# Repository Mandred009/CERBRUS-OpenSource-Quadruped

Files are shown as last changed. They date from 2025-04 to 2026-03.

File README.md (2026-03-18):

<table style="width:100%">
  <tr>
    <th width="50%">Physical Hardware</th>
    <th width="50%">MuJoCo Simulation</th>
  </tr>
  <tr>
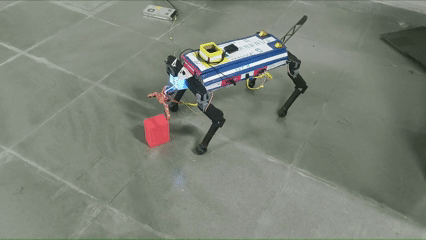
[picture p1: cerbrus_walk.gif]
    <td></td>
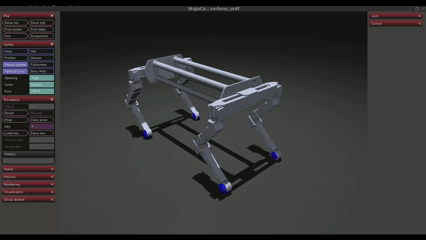
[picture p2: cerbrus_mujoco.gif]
    <td></td>
  </tr>
</table>

# CERBRUS: Open-Source Ant-Inspired Quadruped
**A 14-DoF Bio-Inspired Robot with Front-Mounted Manipulation and ROS 2 Integration. Inspired by nature, engineered for autonomy.**

 



---

## 📋 Overview
Most quadruped robots treat manipulation as a secondary attachment, often resulting in a high center of gravity and reduced stability. **CERBRUS** re-engineers this approach by mimicking **ant morphology**, integrating a **2-DoF gripper at the front "mandibles."** This design optimizes the center of mass for pick-and-place tasks and enables interaction in narrow environments where top-mounted arms traditionally struggle.

> **Note:** This project is currently in active development at the intersection of bio-inspired hardware and autonomous perception.

---

## ✨ Key Features
* **Ant-Inspired Morphology:** Front-mounted 2-DoF gripper for stable, organic manipulation.
* **14 Degrees of Freedom:** 3-DoF per leg + 2-DoF gripper for high-fidelity gait control and interaction.
* **ROS 2 Native:** Built on **Jazzy Jalisco**, utilizing a modular node architecture for telemetry, control, and perception.
* **Active Balancing:** Real-time PID-based posture correction using **BNO055 IMU** data for terrain adaptation.
* **Edge-Ready Compute:** Powered by **Raspberry Pi 5** for high-level logic and Arduino microcontrollers for low-level actuator PWM.

---

## 🛠 Hardware Architecture

| Component | Specification |
| :--- | :--- |
| **Main Processor** | Raspberry Pi 5 (8GB) running Ubuntu 24.04 |
| **Microcontrollers** | Arduino Mega (Gait/Leg Kinematics) & Arduino Nano (Gripper) |
| **Sensors** | Bosch BNO055 (9-axis IMU), Voltage/Current Telemetry |
| **Actuators** | 14x High-torque Metal Gear Servos |
| **Communication** | HC-12 Long Range Radio / Custom Handheld Controller |
| **Chassis** | Modular 3D-printed design optimized for payload-to-weight ratio |

---

## 💻 Software & Installation

### Prerequisites
* **OS:** Ubuntu 24.04 (Noble Numbat)
* **Middleware:** ROS 2 Jazzy Jalisco
* **Language:** Python 3.10+ / C++ 17

### Quick Start
```bash
# Please read the report pasted at the bottom of this page for more details on technical implementation and software design.

# Clone the repository and submodules
git clone --recursive [https://github.com/Mandred009/CERBRUS-OpenSource-Quadruped.git](https://github.com/Mandred009/CERBRUS-OpenSource-Quadruped.git)
cd CERBRUS-OpenSource-Quadruped

# Install ROS 2 dependencies
rosdep install --from-paths src --ignore-src -r -y

# Build the workspace
colcon build --symlink-install
source install/setup.bash

# Launch the core controller and telemetry
ros2 launch cerbrus_bringup cerbrus.launch.py

# To Launch the Mujoco sim
ros2 launch cerbrus_sim robot.launch.py
```
### Research & Development Roadmap
CERBRUS serves as an open-source testbed for several advanced robotics research trajectories:

[1] Perception-Driven Grasping: Integrating lightweight Vision-Language Models (VLMs) for semantic object identification and autonomous retrieval.

[2] Unsupervised Navigation: Utilizing edge-based topology prediction and structural manifolds for obstacle avoidance in unstructured environments.

[3] Reinforcement Learning: Developing high-fidelity digital twins in NVIDIA Isaac Sim to train gait policies for deployment on physical hardware

and much more.

### Contributing
We welcome contributions from the robotics community! Whether it’s gait optimization, CV-based SLAM, or hardware refinement:

1) Fork the repository.

2) Create your Feature Branch (git checkout -b feature/AmazingFeature).

3) Commit your changes (git commit -m 'Add some AmazingFeature').

4) Push to the branch (git push origin feature/AmazingFeature).

5) Open a Pull Request.

[Demo Video](https://youtu.be/7aDOSGi9X7s?si=jsZ_k7eUMPky-3Gf)

[Cerbrus Report](https://drive.google.com/file/d/167SGrlnD2wC8xEmvnSjF_YPM4pek4O9T/view?usp=sharing)

[CAD Files](https://drive.google.com/drive/folders/1i38UzL1JV2BpZAZQdjU2TJO_qoiLwZAB?usp=sharing)

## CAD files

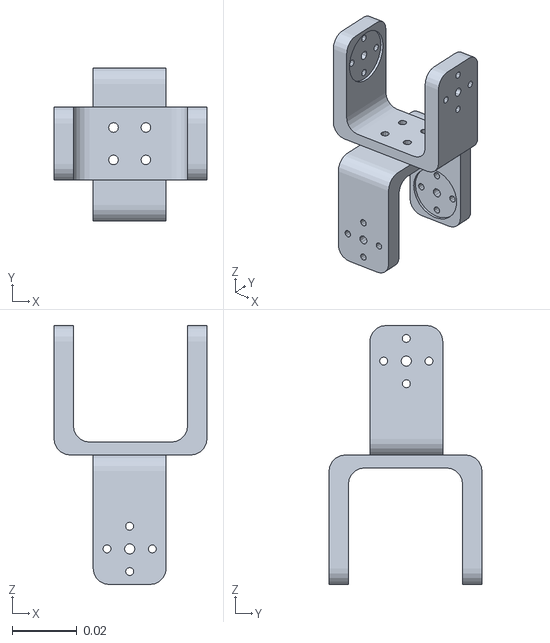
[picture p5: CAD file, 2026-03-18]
src/cerbrus_sim/urdf/meshes/back_right_b_link.STL
0.0472 x 0.0472 x 0.08

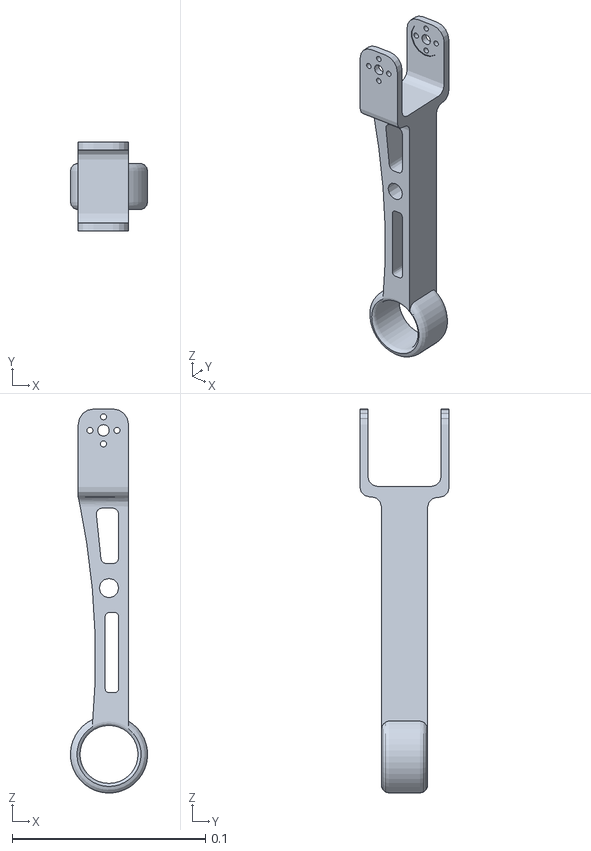
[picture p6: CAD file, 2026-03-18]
src/cerbrus_sim/urdf/meshes/front_right_ll_link.STL
0.0399 x 0.0463 x 0.199

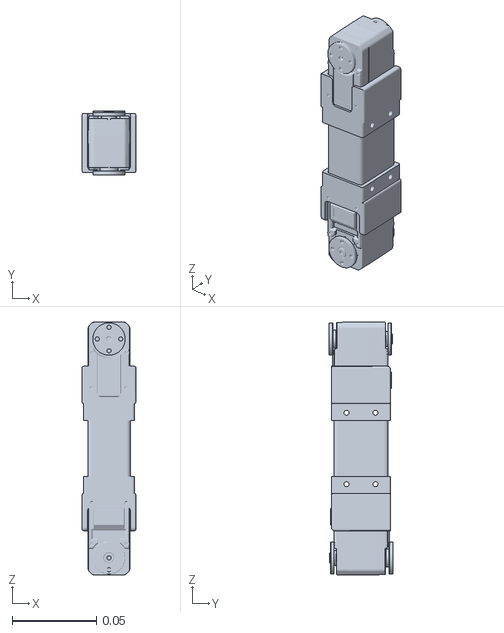
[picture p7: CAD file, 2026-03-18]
src/cerbrus_sim/urdf/meshes/back_left_ul_link.STL
0.032 x 0.0382 x 0.15

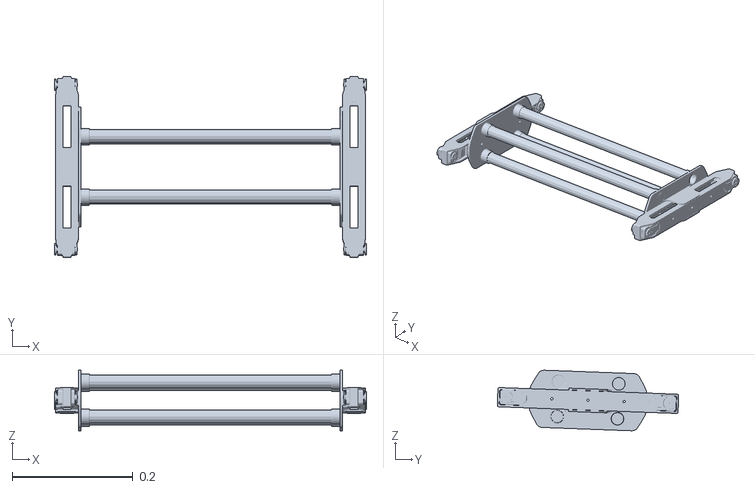
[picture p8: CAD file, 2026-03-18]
src/cerbrus_sim/urdf/meshes/base_link.STL
0.517 x 0.301 x 0.101

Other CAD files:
src/cerbrus_sim/urdf/meshes/back_left_b_link.STL
src/cerbrus_sim/urdf/meshes/back_right_ll_link.STL
src/cerbrus_sim/urdf/meshes/front_right_ul_link.STL
src/cerbrus_sim/urdf/meshes/back_right_ul_link.STL
src/cerbrus_sim/urdf/meshes/front_left_ll_link.STL
src/cerbrus_sim/urdf/meshes/front_left_ul_link.STL
src/cerbrus_sim/urdf/meshes/front_right_b_link.STL
src/cerbrus_sim/urdf/meshes/back_left_ll_link.STL
src/cerbrus_sim/urdf/meshes/front_left_b_link.STL

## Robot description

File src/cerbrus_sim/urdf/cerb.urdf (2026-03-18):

<?xml version="1.0" encoding="utf-8"?>
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
<robot name="cerbrus_urdf">
    <mujoco>
        <compiler meshdir="/home/mandred/cerbrus_ws/src/cerbrus_description/meshes/" balanceinertia="true" discardvisual="false" />
  </mujoco>
  <link name="base_link">
    <inertial>
      <origin xyz="0.2637 0.13624 -0.0045945" rpy="0 0 0" />
      <mass value="1.2203" />
      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
    </inertial>
    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
  </link>

  <link name="front_left_b_link">
    <inertial>
      <origin xyz="0.023501 -0.00012609 -0.029" rpy="0 0 0" />
      <mass value="0.025843" />
      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
    </inertial>
    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
  </link>
  <joint name="front_left_b_joint" type="revolute">
    <origin xyz="0.48015 0.27243 -0.010182" rpy="0 0 0" />
    <parent link="base_link" />
    <child link="front_left_b_link" />
    <axis xyz="1 0 0" />
    <limit lower="-1.57" upper="1.57" effort="100" velocity="4" />
  </joint>
  <link name="front_left_ul_link">
    <inertial>
      <origin xyz="0.00012183 -0.018126 -0.065002" rpy="0 0 0" />
      <mass value="0.1273" />
      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
    </inertial>
    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
  </link>
  <joint name="front_left_ul_joint" type="revolute">
    <origin xyz="0.023375 0.018375 -0.058" rpy="0 0.065641 0" />
    <parent link="front_left_b_link" />
    <child link="front_left_ul_link" />
    <axis xyz="0 1 0" />
    <limit lower="-1.57" upper="1.57" effort="100" velocity="4" />
  </joint>
  <link name="front_left_ll_link">
    <inertial>
      <origin xyz="0.0022913 -0.023105 -0.088631" rpy="0 0 0" />
      <mass value="0.064388" />
      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
    </inertial>
    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
  </link>
  <joint name="front_left_ll_joint" type="revolute">
    <origin xyz="0 0.004658 -0.13" rpy="0 -0.028284 0" />
    <parent link="front_left_ul_link" />
    <child link="front_left_ll_link" />
    <axis xyz="0 1 0" />
    <limit lower="-1.57" upper="1.57" effort="100" velocity="4" />
  </joint>
  <link name="front_right_b_link">
    <inertial>
      <origin xyz="0.023501 -0.00012609 -0.029" rpy="0 0 0" />
      <mass value="0.025843" />
      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
    </inertial>
    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
  </link>
  <joint name="front_right_b_joint" type="revolute">
    <origin xyz="0.48015 0 0" rpy="0 0 0" />
    <parent link="base_link" />
    <child link="front_right_b_link" />
    <axis xyz="1 0 0" />
    <limit lower="-1.57" upper="1.57" effort="100" velocity="4" />
  </joint>
  <link name="front_right_ul_link">
    <inertial>
      <origin xyz="0.00012183 0.019124 -0.065002" rpy="0 0 0" />
      <mass value="0.1273" />
      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
    </inertial>
    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
  </link>
  <joint name="front_right_ul_joint" type="revolute">
    <origin xyz="0.023375 -0.018875 -0.058" rpy="0 0.065641 0" />
    <parent link="front_right_b_link" />
    <child link="front_right_ul_link" />
    <axis xyz="0 1 0" />
    <limit lower="-1.57" upper="1.57" effort="100" velocity="4" />
  </joint>
  <link name="front_right_ll_link">
    <inertial>
      <origin xyz="0.0022913 0.023145 -0.088631" rpy="0 0 0" />
      <mass value="0.064388" />
      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
    </inertial>
    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
  </link>
  <joint name="front_right_ll_joint" type="revolute">
    <origin xyz="0 -0.002742 -0.13" rpy="0 -0.028284 0" />
    <parent link="front_right_ul_link" />
    <child link="front_right_ll_link" />
    <axis xyz="0 1 0" />
    <limit lower="-1.57" upper="1.57" effort="100" velocity="4" />
  </joint>
  <link name="back_left_b_link">
    <inertial>
      <origin xyz="0.023501 -0.00012609 -0.029" rpy="0 0 0" />
      <mass value="0.025843" />
      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
    </inertial>
    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
  </link>
  <joint name="back_left_b_joint" type="revolute">
    <origin xyz="0 0.27243 -0.010182" rpy="-0.060911 0 0" />
    <parent link="base_link" />
    <child link="back_left_b_link" />
    <axis xyz="1 0 0" />
    <limit lower="-1.57" upper="1.57" effort="100" velocity="4" />
  </joint>
  <link name="back_left_ul_link">
    <inertial>
      <origin xyz="0.00012183 -0.018126 -0.065002" rpy="0 0 0" />
      <mass value="0.1273" />
      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
    </inertial>
    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
  </link>
  <joint name="back_left_ul_joint" type="revolute">
    <origin xyz="0.023375 0.018375 -0.058" rpy="0 -0.092957 0" />
    <parent link="back_left_b_link" />
    <child link="back_left_ul_link" />
    <axis xyz="0 1 0" />
    <limit lower="-1.57" upper="1.57" effort="100" velocity="4" />
  </joint>
  <link name="back_left_ll_link">
    <inertial>
      <origin xyz="0.0022913 -0.023105 -0.088631" rpy="0 0 0" />
      <mass value="0.064388" />
      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
    </inertial>
    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
  </link>
  <joint name="back_left_ll_joint" type="revolute">
    <origin xyz="0 0.004658 -0.13" rpy="0 0.13031 0" />
    <parent link="back_left_ul_link" />
    <child link="back_left_ll_link" />
    <axis xyz="0 1 0" />
    <limit lower="-1.57" upper="1.57" effort="100" velocity="4" />
  </joint>
  <link name="back_right_b_link">
    <inertial>
      <origin xyz="0.023501 -0.00012609 -0.029" rpy="0 0 0" />
      <mass value="0.025843" />
      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
    </inertial>
    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
  </link>
  <joint name="back_right_b_joint" type="revolute">
    <origin xyz="0 0 0" rpy="0 0 0" />
    <parent link="base_link" />
    <child link="back_right_b_link" />
    <axis xyz="1 0 0" />
    <limit lower="-1.57" upper="1.57" effort="100" velocity="4" />
  </joint>
  <link name="back_right_ul_link">
    <inertial>
      <origin xyz="0.00012183 0.019124 -0.065002" rpy="0 0 0" />
      <mass value="0.1273" />
      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
    </inertial>
    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
  </link>
  <joint name="back_right_ul_joint" type="revolute">
    <origin xyz="0.023375 -0.018875 -0.058" rpy="0 0.065641 0" />
    <parent link="back_right_b_link" />
    <child link="back_right_ul_link" />
    <axis xyz="0 1 0" />
    <limit lower="-1.57" upper="1.57" effort="100" velocity="4" />
  </joint>
  <link name="back_right_ll_link">
    <inertial>
      <origin xyz="0.0022913 0.023145 -0.088631" rpy="0 0 0" />
      <mass value="0.064388" />
      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
    </inertial>
    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
  </link>
  <joint name="back_right_ll_joint" type="revolute">
    <origin xyz="0 -0.002742 -0.13" rpy="0 -0.028284 0" />
    <parent link="back_right_ul_link" />
    <child link="back_right_ll_link" />
    <axis xyz="0 1 0" />
    <limit lower="-1.57" upper="1.57" effort="100" velocity="4" />
  </joint>
</robot>

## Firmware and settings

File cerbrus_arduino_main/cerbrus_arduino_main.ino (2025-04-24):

// Arduino Script for main servo controller arduino mega

#include "quad_servo.h"
#include <Servo.h>

#define CALI_BUTTON 2

int cali_flag=0; // Check if calibration button is on

float input_values[20]; //starting and ending value is -1 for checking correct transfer
byte* ddata = reinterpret_cast<byte*>(&input_values);
size_t pcDataLen= sizeof(input_values);
bool newData=false;

Servo base_servo;
Servo effector_servo;

// The mouth arm servo limits
const int effector_servo_min=50;
const int effector_servo_max=130;

const int base_servo_min=0;
const int base_servo_max=180;

void setup() {
  // put your setup code here, to run once:
  Serial.begin(1000000);
  Serial1.begin(1000000);
  st.pSerial = &Serial1;
  pinMode(CALI_BUTTON,INPUT_PULLUP);
  pinMode(LED_BUILTIN,OUTPUT);
  Serial.setTimeout(100);

  base_servo.attach(5);
  effector_servo.attach(6);
  
  delay(1000);
  
}


void loop(){
  int button=digitalRead(CALI_BUTTON);

  if(button==0){
    cali_flag=1-cali_flag;
    digitalWrite(LED_BUILTIN,cali_flag);
    delay(1000);
  }
  if(cali_flag==1){
      calibration_pos();
    }
    else{
      checkForNewData();
  if(newData==true){
    if(input_values[0]==-1.0 && input_values[19]==-1.0){
      stable_state(all_leg,4,input_values[1],input_values[2],input_values[3],input_values[4],
                  input_values[5],input_values[6],input_values[7],input_values[8],
                  input_values[9],input_values[10],input_values[11],input_values[12]
                  ,input_values[13],input_values[14],input_values[15],input_values[16]);

      move_mouth_servos(int(trunc(input_values[17])),int(trunc(input_values[18])));
    }
    
    newData=false;
  }
      
    }
  
  
}

// Function to check for new data from the serial port
void checkForNewData() {
  if (Serial.available() >= pcDataLen && newData == false) {
    for (byte n = 0; n < pcDataLen; n++) {
      ddata[n] = Serial.read();
    }
    while (Serial.available() > 0) {
      byte dumpByte = Serial.read();
    }
    newData = true;
  }
}

// Function to move the servos
void move_mouth_servos(int pot1, int pot2){

  if(pot1>=0 and pot1<=1023 and pot2>=0 and pot2<=1023){
      int base_servo_angle=map(pot1,0,1023,base_servo_min,base_servo_max);
      int effector_servo_angle=map(pot2,0,1023,effector_servo_min,effector_servo_max);
    
      base_servo.write(base_servo_angle);
      effector_servo.write(effector_servo_angle);
  }

  
  
}

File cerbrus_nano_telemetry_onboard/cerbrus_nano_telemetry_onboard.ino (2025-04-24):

// Arduino nano onboard telemetry script
// Channel 002 and 9600 Baud for HC-12

#include <Wire.h>
#include <SPI.h>

#include <SoftwareSerial.h>

SoftwareSerial HC12(3, 2);


String receivedData="";

const byte numChars=128;
char receivedChars[numChars]="null";
boolean newData=false;

#define MAX_VALUES 8  // Maximum number of values you expect

String extractedValues[MAX_VALUES]= {""};  // Array to hold the extracted values
int extractedCount = 0;  // Keeps track of the number of extracted values


void setup () 
{
  
  Serial.begin(9600);
  HC12.begin(9600);
  while(true){
    String cmd_="null";
    if(Serial.available()>0){
      cmd_=Serial.readStringUntil('\n');
      cmd_.trim();
    }
    if(cmd_=="start"){
      break;
    }
  }

    
}  // end of setup

void loop () 
{

  recvWithStartEndMarkers();
  newData=false;

  if(countOccurrences(receivedChars,'(')==0 && countOccurrences(receivedChars,')')==0 && countOccurrences(receivedChars,',')==MAX_VALUES-1)
  {
    send_data();

  
    extractValues(receivedChars);  // Extract values from the string
    
      
    extractedCount=0;
  }
  
  

} 


void send_data(){
  HC12.print('(');
  for(auto i:receivedChars){
    HC12.print(i);
  }
  HC12.print(')');
  HC12.println();
  delay(100);
  
}

void extractValues(const String& input) {
  String temp = input;
  temp.trim();  // Remove any leading or trailing spaces
  
  // Ensure the input starts with '(' and ends with ')'
    // Remove the parentheses
    temp.remove(0, 1);  // Remove the first '('
    temp.remove(temp.length() - 1, 1);  // Remove the last ')'
    
    int startIndex = 0;
    int endIndex;
    extractedCount = 0;  // Reset extracted count

    // Extract values from the string, using commas as delimiters
    while ((endIndex = temp.indexOf(',', startIndex)) != -1 && extractedCount < MAX_VALUES) {
      extractedValues[extractedCount++] = temp.substring(startIndex, endIndex);
      startIndex = endIndex + 1;
    }

    // Extract the last value if there's no comma at the end
    if (startIndex < temp.length() && extractedCount < MAX_VALUES) {
      extractedValues[extractedCount++] = temp.substring(startIndex);
    }

}

// Function to check te incoming serial stream and its enclosing bytes that is '()' in this case
void recvWithStartEndMarkers(){
  static boolean recvInProgress=false;
  static byte ndx=0;
  char startMarker='(';
  char endMarker=')';
  char rc;

  while(Serial.available()>0 && newData==false){
    rc=Serial.read();

    if(recvInProgress==true){
      if(rc!=endMarker){
        receivedChars[ndx]=rc;
        ndx++;
        if(ndx>=numChars){
          ndx=numChars-1;
        }
      }
      else{
        receivedChars[ndx]='\0';
        recvInProgress=false;
        ndx=0;
        newData=true;
      }
    }
    else if(rc==startMarker){
      recvInProgress=true;
    }
  }
}

// Function to count character occurances in a string. For data check
int countOccurrences(const String& input, char target) {
    int count = 0;
    for (int i = 0; i < input.length(); i++) {
        if (input[i] == target) {
            count++;
        }
    }
    return count;
}

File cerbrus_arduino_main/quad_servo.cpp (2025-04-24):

// Leg Servos cpp file

#include "quad_servo.h"

SMS_STS st;


float l1 = 58,l2 = 130.5,l3 = 190; // Leg Link Parameters

byte ID[12] = {5, 6, 4, 7, 13, 15, 8, 1, 10, 12, 9, 11}; // Servo IDS

byte ACC[12] = {80,80,80,80,80,80,80,80,80,80,80,80}; // Servo Acceleration list

float constraints[4][3][2][2] = {
    // Leg 1
    {
        {{1006, 3054}, {0, 180}}, // Hip joint servo range and angle range 
        {{3174, 1126}, {90, -90}}, // Knee joint servo range and angle range
        {{2924, 876}, {90, -90}}  // Ankle joint servo range and angle range
    },
    // Leg 2
    {
        {{3104, 1056}, {0, 180}}, // Hip joint servo range and angle range
        {{1024, 3072}, {-90, 90}}, // Knee joint servo range and angle range
        {{3072, 1024}, {-90, 90}}  // Ankle joint servo range and angle range
    },
    // Leg 3
    {
        {{3144, 1048}, {0, 180}}, // Hip joint servo range and angle range
        {{1026, 3074}, {-90, 90}}, // Knee joint servo range and angle range
        {{3274, 1226}, {-90, 90}}  // Ankle joint servo range and angle range
    },
    // Leg 4
    {
        {{1024, 3072}, {0, 180}}, // Hip joint servo range and angle range
        {{3072, 1024}, {90, -90}}, // Knee joint servo range and angle range
        {{3144, 1096}, {-90, 90}}  // Ankle joint servo range and angle range
    }
};


int all_leg[4]={0,1,2,3};



void stable_state(int legs_to_move[], int num_legs,float h1, float h2, float h3, float h4, float z1, float z2, float z3, float z4, float y1, float y2, float y3, float y4, float vel1, float vel2, float vel3, float vel4) {
    // Define the stable X and Z positions

    float ptsx[] = {h1, h2, h3, h4};  // Leg 1, 2, 3, 4 X positions
    float ptsz[] = {z1, z2, z3, z4};  // Leg 1, 2, 3, 4 Z positions
    float ptsy[] = {20+y1, 20+y2, 20+y3, 20+y4}; // +20 to widen the leg base and make side motion possible
    float velocity[] = {vel1, vel2, vel3, vel4};  // Speed for each leg

    u16 Speed_all[num_legs*3];
    float theta_all[num_legs*3];
    float theta[3];

    byte selected_IDs[num_legs*3]; 

    byte acc[num_legs*3]; 

    // Loop through the specified legs to move
    for (int i = 0; i < num_legs; i++) {
        int leg = legs_to_move[i];  // Get the leg index from the input array
        float x = ptsx[leg];
        float z = ptsz[leg];
        float y = ptsy[leg];;

        ik(x, y, z, constraints, theta, leg);  // Calculate inverse kinematics for this leg

        // Store the computed joint angles for the selected leg
        theta_all[i * 3 + 0] = theta[0];  // theta1 for current leg
        theta_all[i * 3 + 1] = theta[1];  // theta2 for current leg
        theta_all[i * 3 + 2] = theta[2];  // theta3 for current leg

        // Set the speed for the selected leg
        Speed_all[i * 3 + 0] = velocity[leg];  // Speed for theta1
        Speed_all[i * 3 + 1] = velocity[leg];  // Speed for theta2
        Speed_all[i * 3 + 2] = velocity[leg];  // Speed for theta3

        selected_IDs[i * 3 + 0] = ID[leg*3+0]; 
        selected_IDs[i * 3 + 1] = ID[leg*3+1];  
        selected_IDs[i * 3 + 2] = ID[leg*3+2];  

        acc[i * 3 + 0] = ACC[leg*3+0];  
        acc[i * 3 + 1] = ACC[leg*3+1];  
        acc[i * 3 + 2] = ACC[leg*3+2];  
    }

    // Convert theta_all (float) to s16 (short int)
    s16 theta_all_s16[num_legs*3];
    for (int i = 0; i < num_legs*3; i++) {
        theta_all_s16[i] = (s16)theta_all[i];  // Convert each angle to short integer
    }

    // Synchronize the servo positions
    st.SyncWritePosEx(selected_IDs, num_legs*3, theta_all_s16, Speed_all, acc); 

    
}


int angle_to_servo_converter(float angle, float servo_map[], float angle_map[]) {
    // Calculate the converted servo position
    float converted_servo = servo_map[0] - ((servo_map[0] - servo_map[1]) * (angle_map[0] - angle) / (angle_map[0] - angle_map[1]));
    return abs((int)converted_servo);
}

// Function to perform inverse kinematics and return theta values as an array
void ik(float x, float y, float z, float constraint_list[4][3][2][2], float (&theta)[3], int leg_index) {
    // Select constraints based on the leg index
    float constraint_1[2] = {constraint_list[leg_index][0][0][0], constraint_list[leg_index][0][0][1]}; // Hip servo range
    float constraint_2[2] = {constraint_list[leg_index][1][0][0], constraint_list[leg_index][1][0][1]}; // Knee servo range
    float constraint_3[2] = {constraint_list[leg_index][2][0][0], constraint_list[leg_index][2][0][1]}; // Ankle servo range

    float angle_map_1[2] = {constraint_list[leg_index][0][1][0], constraint_list[leg_index][0][1][1]}; // Hip angle limits
    float angle_map_2[2] = {constraint_list[leg_index][1][1][0], constraint_list[leg_index][1][1][1]}; // Knee angle limits
    float angle_map_3[2] = {constraint_list[leg_index][2][1][0], constraint_list[leg_index][2][1][1]}; // Ankle angle limits

    // Calculate theta1 (hip joint)
    float theta1 = atan2(y, x);
    theta1 = abs(degrees(theta1)); // Convert to degrees

    // Calculate other parameters for IK
    float s = z;
    float r = (sqrt(x * x + y * y) - l1);
    float D = ((r * r) + (s * s) - (l2 * l2) - (l3 * l3)) / (2 * l2 * l3);

    // Calculate theta3 (ankle joint)
    float theta3 = acos(D);

    // Calculate theta2 (knee joint)
    float theta2 = atan2(s, r) - atan2(l3 * sin(theta3), l2 + (l3 * cos(theta3)));

    // Convert theta2 and theta3 to degrees
    float theta2_d = degrees(theta2);
    float theta3_d = degrees(theta3);

    // Convert angles to servo positions using angle_to_servo_converter
    theta[0] = angle_to_servo_converter(theta1, constraint_1, angle_map_1); // Hip joint
    theta[1] = angle_to_servo_converter(theta2_d, constraint_2, angle_map_2); // Knee joint
    theta[2] = angle_to_servo_converter(theta3_d, constraint_3, angle_map_3); // Ankle joint
}

// Change this function values if your calibration center points are different
void calibration_pos(){
  s16 center_pt[12]={2030,2150,1900,2080,2048,2048,2096,2050,2250,2048,2048,2120};
  u16 Speed[12]={500,500,500,500,500,500,500,500,500,500,500,500};
  st.SyncWritePosEx(ID, 12, center_pt, Speed , ACC); 
}

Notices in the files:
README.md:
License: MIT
